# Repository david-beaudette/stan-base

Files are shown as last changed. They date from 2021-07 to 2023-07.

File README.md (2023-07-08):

### Install RPi Pico SDK
In a personal folder called projects (could be other):
```bash
cd ~/projects
mkdir pico
cd pico
git clone -b master https://github.com/raspberrypi/pico-sdk.git
cd pico-sdk
git submodule update --init
cd ..
git clone -b master https://github.com/raspberrypi/pico-examples.git
sudo apt update
sudo apt install cmake gcc-arm-none-eabi libnewlib-arm-none-eabi build-essential
cd pico-examples
mkdir build
cd build
echo "export PICO_SDK_PATH=~/projects/pico-sdk" >> ~/.bashrc
source ~/.bashrc
cmake -DCMAKE_BUILD_TYPE=Debug ..
make -j4

```
### Install OpenOCD and debugger
```bash
cd ~/projects/pico
sudo apt install automake autoconf build-essential texinfo libtool libftdi-dev libusb-1.0-0-dev
git clone https://github.com/raspberrypi/openocd.git --recursive --branch rp2040 --depth=1
cd openocd
./bootstrap
./configure --enable-ftdi --enable-sysfsgpio --enable-bcm2835gpio
make -j4
sudo make install
sudo apt install gdb-multiarch

```
### OpenOCD Setup
Add username to the plugdev group to allow non-sudo access to any USB device:
```bash
echo 'SUBSYSTEM=="usb", MODE="0660", GROUP="plugdev"' | sudo tee /etc/udev/rules.d/00-usb-permissions.rules
udevadm control --reload-rules
sudo usermod -a -G plugdev [username]
```
Log out and back in.

### Debugging session
To debug, start opencd in a seperate terminal in the ~/projects/pico/openocd folder:
```bash
cd ~/projects/pico/openocd
src/openocd -f interface/picoprobe.cfg -f target/rp2040.cfg -s tcl
```

### Current state
## Battery voltage reading
Battery / motor ground is decoupled from digital ground. That is good, however the voltage reading is offset and unreliable because of this. Apparently with proper star grounding the grounds could be connected together without issues. Otherwise the most reliable way of achieving this would be to use a seperate DC/DC converter and ADC on the high-power side, and opto-coupler on the digital link to RP2040. 

## Orientation sensor calibration
A proper procedure to calibrate the BNO055 should be written. Ideally it should be automated when/if the robot can achieve it by itself.

## Serial communication with head
The link between base and head (ROS-based) was not completed yet.

## Stability
Finish test_ctl

## LCD
LCD is not working anymore...

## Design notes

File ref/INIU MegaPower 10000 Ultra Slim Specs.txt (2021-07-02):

Capacity: 10,000 mAh; 37Wh
Output: USB-C: DC 5V/3A Max; USB-A: DC 5V/3A Max
Input: Micro: DC 5V/2A Max; USB C: DC 5V/3A Max Charging Time (via 5V/2A Charger): 5-6 hours
Included in the box: - 10000mAh portable charger*1 - Micro USB cable*1, travel pouch*1, user manual*1
Product materials: PowerBank: rubber covered plastic case with aluminum decorative elements / Cable: TPE, Nylon 
Connections: USB-A 
Length: 5.20 in / 13.21 cm 
Width: 2.70 in / 6.86 cm 
Height: 0.50 in / 1.27 cm 
Weight: 0.46 lbs / 0.21 kg

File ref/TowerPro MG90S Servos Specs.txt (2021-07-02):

Specification:
Weight: 13.4g
Dimension: 22.8×12.2×28.5mm
Stall torque: 1.8kg/cm (4.8V); 2.2kg/cm (6.6V)
Operating speed: 0.10sec/60degree (4.8V); 0.08sec/60degree (6.0V)
Operating voltage: 4.8V
Temperature range: 0 to 55decC
Dead band width: 1us
Power Supply: Through External Adapter
servo wire length: 25 cm
Servo Plug: JR (Fits JR and Futaba)
servo arms &screws included
It’s universal “S” type connector that fits most receivers, including Futaba, JR, Hitec ,GWS, Cirrus, Blue Bird, Blue Arrow, Corona, Berg, Spektrum.
CE &RoHS approved

We have upgraded our servo gear set and shaft to aluminum 6061-T6.
It is stronger and lighter than copper.

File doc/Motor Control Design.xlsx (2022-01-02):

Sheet: Constants
Clock Frequency (Hz) | 1000000
Steps per turn | 200
Microsteps per step | 8
Degrees per step | 1.8

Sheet: Speed
Pulse period (s) | Pulse ticks | Counter compare value | Overflow target | Pulses per sec | Steps per sec | Rotation rate (deg/s) | Result deg for 1 s | Rev per sec | Rotation rate (rad/s) | Pace (s/rad) | T std dev | Jitter (%)
0.000119516 | 119.516 | 119.516 | 0 | 8367.081 | 1045.885 | 1882.593 | 1882.800 | 5.229425349 | 32.8574 | 0.030 | 4.50596e-07 | 0.38%
0.008728 | 8728 | 8728 | 0 | 114.574 | 14.322 | 25.779 | 25.200 | 0.07160861595 | 0.4499 | 2.223 | 4.4247e-07 | 0.01%
0.015342 | 15342 | 15342 | 0 | 65.181 | 8.148 | 14.666 | 14.400 | 0.04073784383 | 0.2560 | 3.907 | 3.4638e-07 | 0.002257723895%
0.061367 | 61367 | 61367 | 0 | 16.295 | 2.037 | 3.666 | 3.600 | 0.01018462692 | 0.0640 | 15.627 | 2.9032e-07 | 0.0004730881418%

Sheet: Test Output
Speed update:
speed_f32 32.86
pol ticks tgt (f32) 956.02
pol ticks tgt 956
pol ticks cur 0
current timer value 27786
next compare value 28742
num overflows 0
OCR1A value 28742
TIMSK value 6
Left motor is stopped (current pos 1882.80 deg).
Right motor is stopped (current pos 27.00 deg).
Speed update:
speed_f32 0.45
pol ticks tgt (f32) 69813.18
pol ticks tgt 69813
pol ticks cur 0
current timer value 24616
next compare value 94429
num overflows 1
OCR1A value 28893
TIMSK value 6
Left motor is stopped (current pos 25.20 deg).
Right motor is stopped (current pos 27.00 deg).
Speed update:
speed_f32 0.26
pol ticks tgt (f32) 122718.46
pol ticks tgt 122718
pol ticks cur 0
current timer value 18599
next compare value 141317
num overflows 2
OCR1A value 10245
TIMSK value 6
Left motor is stopped (current pos 14.40 deg).
Right motor is stopped (current pos 27.00 deg).
Speed update:
speed_f32 0.06
pol ticks tgt (f32) 490873.84
pol ticks cur 0
current timer value 12622
next compare value 503495
num overflows 7
OCR1A value 44743
TIMSK value 6
Left motor is stopped (current pos 3.60 deg).
Right motor is stopped (current pos 27.00 deg).

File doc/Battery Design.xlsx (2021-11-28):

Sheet: Feuil1
State of Charge (%) | Voltage (V) | Analog count | F0 | F1 | F2 | F3 | Diff SoC (%)
100 | 12.6 | 3755 | 0.00000053 | -0.00396 | 7.46484 | 99.52417005 | 0.48
95 | 12.45 | 3711.309524 | 0.00000053 | -0.00399 | 7.55132 | 94.32312696 | 0.68
90 | 12.33 | 3676.357143 | 0.00000053 | -0.00401 | 7.62197 | 90.12365534 | -0.12
85 | 12.25 | 3653.055556 | 0.00000053 | -0.00402 | 7.66980 | 87.23095446 | -2.23
80 | 12.07 | 3600.626984 | 0.00000053 | -0.00405 | 7.77953 | 80.21527967 | -0.22
75 | 11.95 | 3565.674603 | 0.00000053 | -0.00406 | 7.85432 | 74.96738226 | 0.03
70 | 11.86 | 3539.460317 | 0.00000053 | -0.00408 | 7.91126 | 70.63443217 | -0.63
65 | 11.74 | 3504.507937 | 0.00000053 | -0.00410 | 7.98833 | 64.217946 | 0.78
60 | 11.62 | 3469.555556 | 0.00000053 | -0.00412 | 8.06671 | 56.9453805 | 3.05
55 | 11.56 | 3452.079365 | 0.00000053 | -0.00413 | 8.10639 | 52.9452693 | 2.05
50 | 11.51 | 3437.515873 | 0.00000053 | -0.00413 | 8.13971 | 49.40985029 | 0.59
45 | 11.45 | 3420.039683 | 0.00000053 | -0.00414 | 8.17999 | 44.91013486 | 0.09
40 | 11.39 | 3402.563492 | 0.00000053 | -0.00415 | 8.22059 | 40.11365542 | -0.11
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

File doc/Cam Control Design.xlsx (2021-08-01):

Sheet: Speed
Prescaler idx | Prescaler | Tick duration (s) | Tick duration (ns) | TOF Period (s) | Number of TOF | Integer num TOF | Achievable period (s) | PWM period error (%) | PWM resolution (%)
1 | 2 | 0.000000125 | 125 | 0.000032 | 625.0000 | 625 | 0.0200000 | 0.0% | 0.0006%
2 | 4 | 0.000000250 | 250 | 0.000064 | 312.5000 | 312 | 0.0199680 | 0.2% | 0.0013%
3 | 8 | 0.000000500 | 500 | 0.000128 | 156.2500 | 156 | 0.0199680 | 0.2% | 0.0025%
4 | 16 | 0.000001000 | 1000 | 0.000256 | 78.1250 | 78 | 0.0199680 | 0.2% | 0.0050%
5 | 32 | 0.000002000 | 2000 | 0.000512 | 39.0625 | 39 | 0.0199680 | 0.2% | 0.0100%
6 | 64 | 0.000004000 | 4000 | 0.001024 | 19.5312 | 19 | 0.0194560 | 2.7% | 0.0206%
7 | 128 | 0.000008000 | 8000 | 0.002048 | 9.7656 | 9 | 0.0184320 | 7.8% | 0.0434%
8 | 256 | 0.000016000 | 16000 | 0.004096 | 4.8828 | 4 | 0.0163840 | 18.1% | 0.0977%
9 | 512 | 0.000032000 | 32000 | 0.008192 | 2.4414 | 2 | 0.0163840 | 18.1% | 0.1953%
10 | 1024 | 0.000064000 | 64000 | 0.016384 | 1.2207 | 1 | 0.0163840 | 18.1% | 0.3906%
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

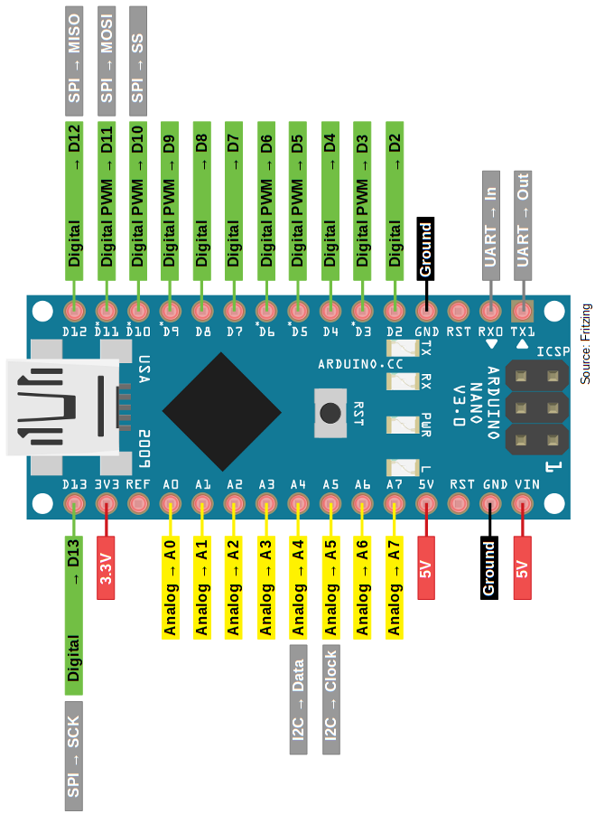
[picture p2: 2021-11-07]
ref/ArduinoNano/Arduino-Nano-Pinout-1.png

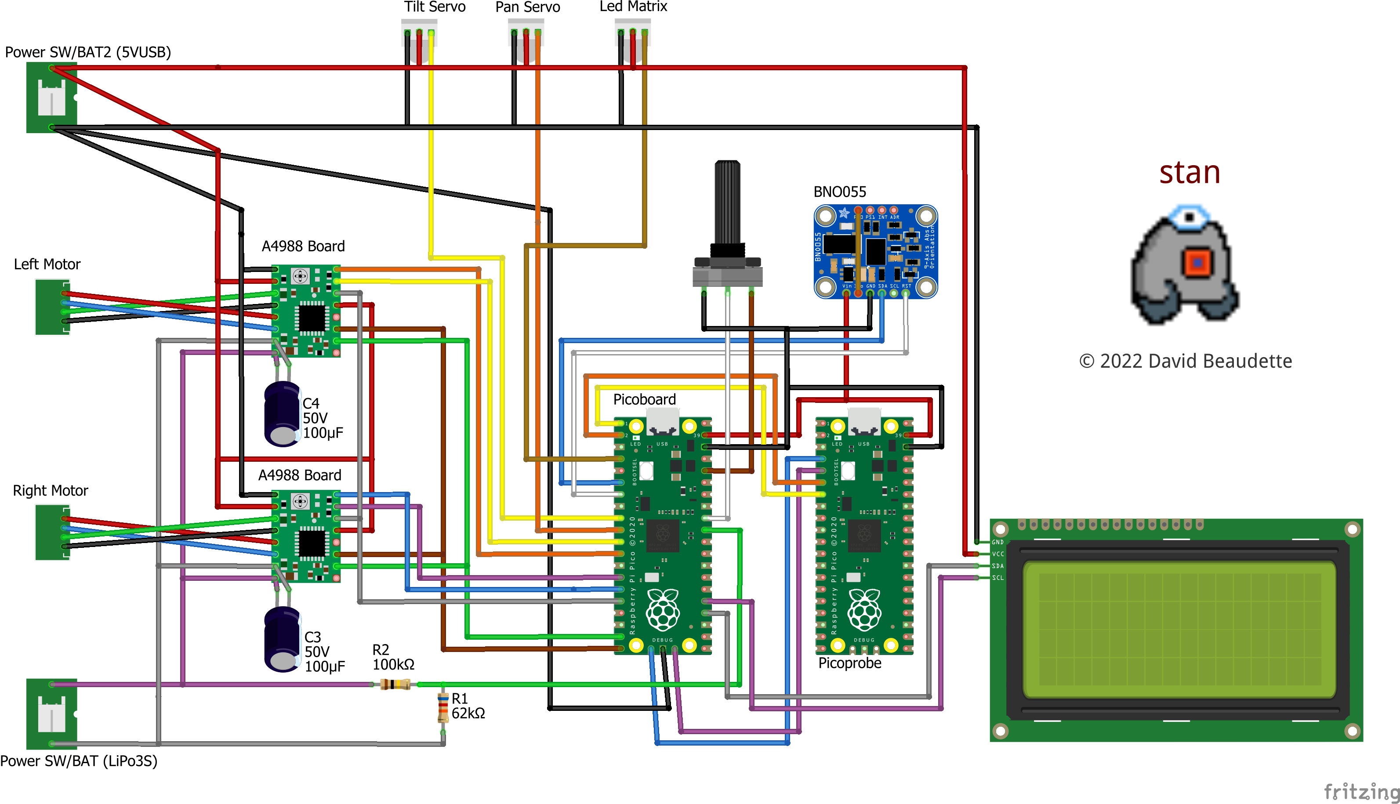
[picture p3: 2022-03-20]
doc/InterconnexionDiagram.png

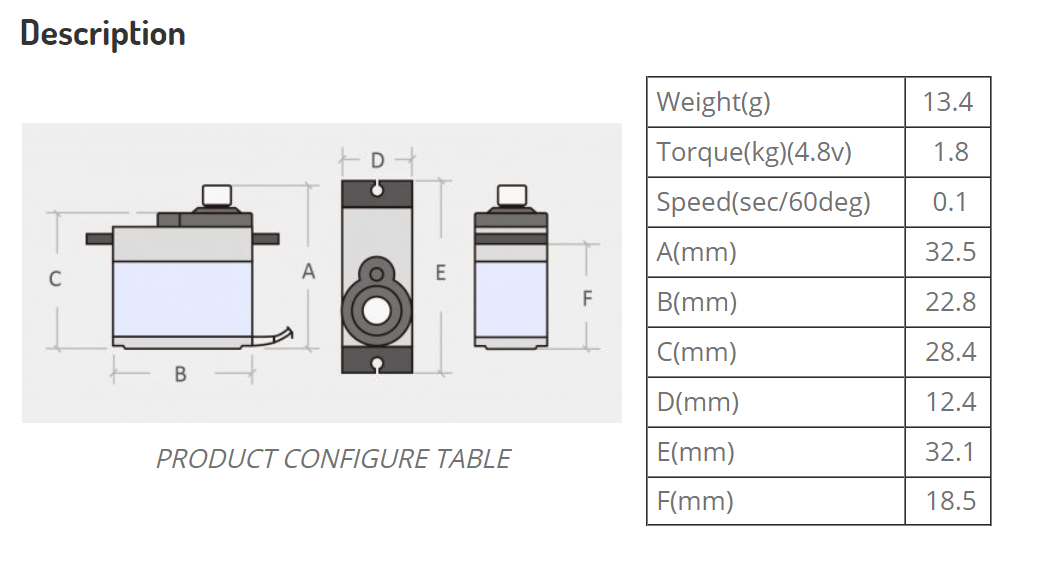
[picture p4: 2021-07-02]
ref/TowerPro MG90S Servos Dimensions.png

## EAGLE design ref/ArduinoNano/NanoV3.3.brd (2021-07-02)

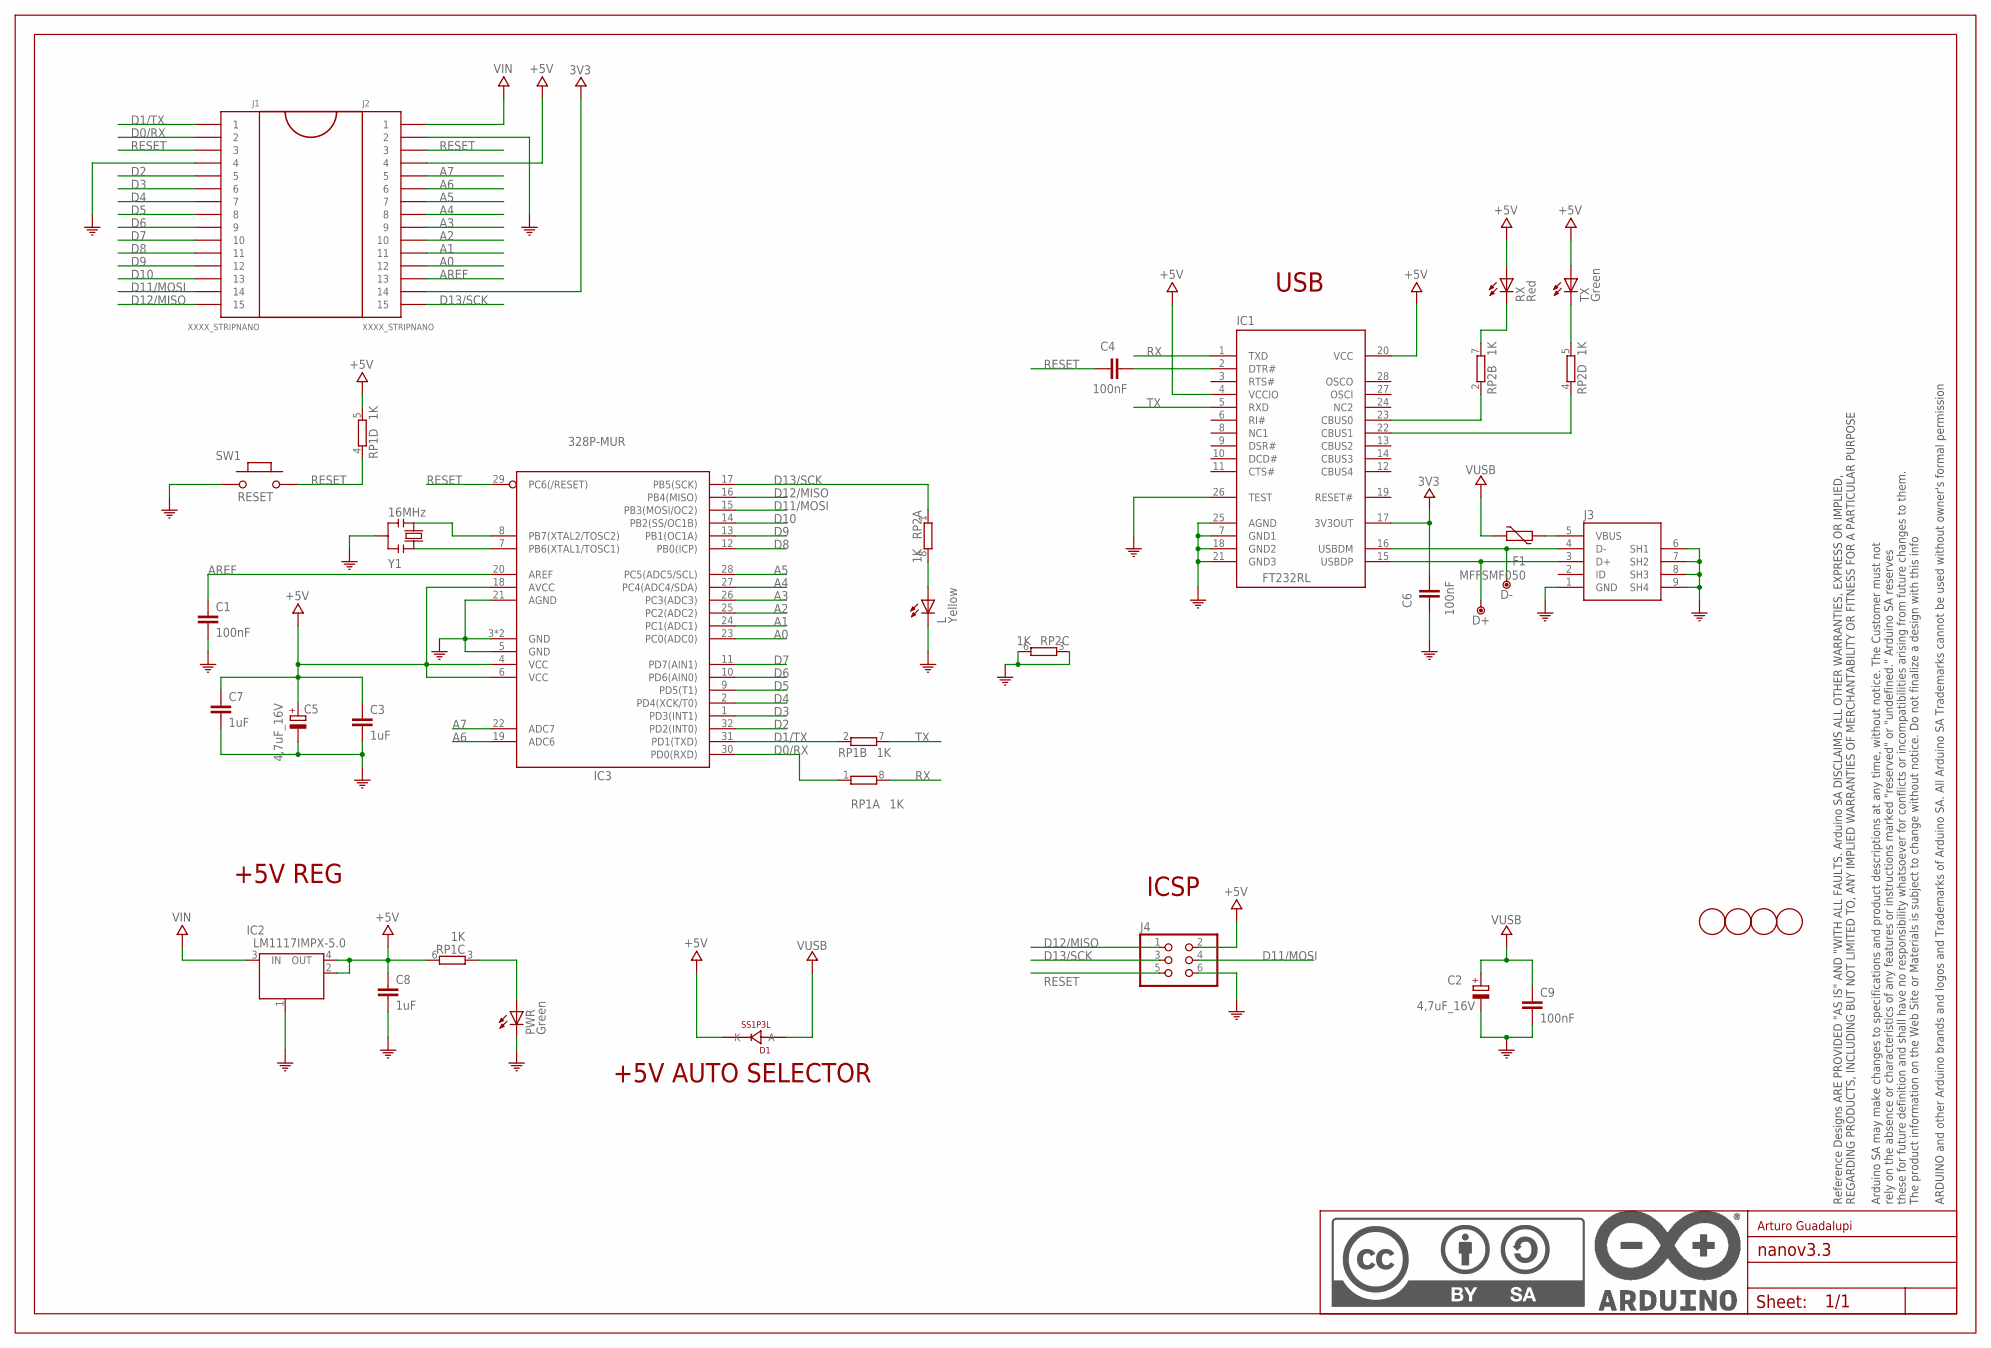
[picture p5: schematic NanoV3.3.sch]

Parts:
C1, C4, C6, C9: 100nF; C0603-ROUND
C2, C5: 4,7uF_16V; TAN-A
C3, C7, C8: 1uF; C0603-ROUND
D1: SS1P3L; DO220AAL
D+: DNP; TP-1.00MM
D-: DNP; TP-1.00MM
F1: MFFSMF050; 0603-1608X90N
FRAME1: DNP; FRAME
IC1: FT232RL; SSOP28
IC2: LM1117IMPX-5.0; LINEAR_SOT223
IC3: 328P-MUR; VQFN32
J1, J2: XXXX_STRIPNANO; HEAD15-NOSS
J3: 0219_14850; USB-MINI-B_2
J4: 0114_PH254-203DF118A00V; 2X03
L: Yellow; CHIPLED_0805
PWR: Green; CHIPLED_0805
RP1, RP2: 1K; CAY16
RX: Red; CHIPLED_0805
SW1: RESET; SMD_157SW
TX: Green; CHIPLED_0805
U$4, U$5, U$53, U$54: DNP; FD-1-1.5
Y1: 16MHz; RESONATOR

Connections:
3V3: C6.2, IC1.17 (3V3OUT), J2.14
+5V: C3.1, C5.1 (+), C7.1, C8.1, D1.P$1 (K), IC1.4 (VCCIO), IC1.20 (VCC), IC2.2 (OUT), IC2.4 (OUT), IC3.4 (VCC), IC3.6 (VCC), IC3.18 (AVCC), J2.4, J4.2, RP1.5 (2), RP1.6 (2), RX.A, TX.A
A0: IC3.23 (PC0(ADC0)), J2.12
A1: IC3.24 (PC1(ADC1)), J2.11
A2: IC3.25 (PC2(ADC2)), J2.10
A3: IC3.26 (PC3(ADC3)), J2.9
A4: IC3.27 (PC4(ADC4/SDA)), J2.8
A5: IC3.28 (PC5(ADC5/SCL)), J2.7
A6: IC3.19 (ADC6), J2.6
A7: IC3.22 (ADC7), J2.5
AREF: C1.1, IC3.20 (AREF), J2.13
COM: C1.2, C2.2 (-), C3.2, C5.2 (-), C6.1, C7.2, C8.2, C9.2, IC1.7 (GND1), IC1.18 (GND2), IC1.21 (GND3), IC1.25 (AGND), IC1.26 (TEST), IC2.1 (GND/ADJ), IC3.3 (GND), IC3.5 (GND), IC3.21 (AGND), IC3.33 (GND), J1.4, J2.2, J3.1 (GND), J3.6 (SH1), J3.7 (SH2), J3.8 (SH3), J3.9 (SH4), J4.6, L.C, PWR.C, RP2.3 (1), RP2.6 (2), SW1.1, Y1.2
D0/RX: IC3.30 (PD0(RXD)), J1.2, RP1.1
D1/TX: IC3.31 (PD1(TXD)), J1.1, RP1.2 (1)
D2: IC3.32 (PD2(INT0)), J1.5
D3: IC3.1 (PD3(INT1)), J1.6
D4: IC3.2 (PD4(XCK/T0)), J1.7
D5: IC3.9 (PD5(T1)), J1.8
D6: IC3.10 (PD6(AIN0)), J1.9
D7: IC3.11 (PD7(AIN1)), J1.10
D8: IC3.12 (PB0(ICP)), J1.11
D9: IC3.13 (PB1(OC1A)), J1.12
D10: IC3.14 (PB2(SS/OC1B)), J1.13
D11/MOSI: IC3.15 (PB3(MOSI/OC2)), J1.14, J4.4
D12/MISO: IC3.16 (PB4(MISO)), J1.15, J4.1
D13/SCK: IC3.17 (PB5(SCK)), J2.15, J4.3, RP2.1
unnamed: IC3.8 (PB7(XTAL2/TOSC2)), Y1.3
unnamed: IC3.7 (PB6(XTAL1/TOSC1)), Y1.1
unnamed: PWR.A, RP1.3 (1)
unnamed: C4.2, IC1.2 (DTR#)
unnamed: D+.X, IC1.15 (USBDP), J3.3 (D+)
unnamed: D-.X, IC1.16 (USBDM), J3.4 (D-)
unnamed: L.A, RP2.8 (2)
unnamed: IC1.23 (CBUS0), RP2.2 (1)
unnamed: IC1.22 (CBUS1), RP2.4 (1)
unnamed: RP2.5 (2), TX.C
unnamed: F1.2, J3.5 (VBUS)
unnamed: RP2.7 (2), RX.C
RESET: C4.1, IC3.29 (PC6(/RESET)), J1.3, J2.3, J4.5, RP1.4 (1), SW1.2
RX: IC1.1 (TXD), RP1.8 (2)
TX: IC1.5 (RXD), RP1.7 (2)
VIN: IC2.3 (IN), J2.1
VUSB: C2.1 (+), C9.1, D1.P$2 (A), F1.1

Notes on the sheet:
+5V REG
ICSP
USB
+5V AUTO SELECTOR
Arturo Guadalupi



Board: 2 copper layers, 43.2 x 17.8 mm, 33 parts (17 on the bottom side), 43 nets.

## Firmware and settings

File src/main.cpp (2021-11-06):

/** STAN THE STANDING ROBOT
   Program for the base / low-level controller 
   by David Beaudette   
**/

// Libraries
#include "Arduino.h"
#include "TaskScheduler.h"

// Project headers
#include "nav.h"
#include "ctl.h"
#include "cam.h"
#include "bat.h"
#include "PID_v1.h"
#include "Base2Head.hpp"
#include "Head2Base.hpp"
#include "fletcher_impl.hpp"

// Function declaration
void gnc_task_run();
void blink();
void pub_slow();
void pub_fast();
void check_sys();

// Serial callbacks
void serial_cmd_recv();
size_t read_bytes(byte *buffer, size_t n);

// Task configuration
float gnc_task_dt = 0.01f;

Scheduler runner;

Task gnc_task((int)(gnc_task_dt * 1000.0f), TASK_FOREVER, &gnc_task_run);
Task blink_task(500, TASK_FOREVER, &blink);
Task pub_slow_task(1000, TASK_FOREVER, &pub_slow);
Task pub_fast_task(10, TASK_FOREVER, &pub_fast);
Task check_sys_task(1000, TASK_FOREVER, &check_sys);

// Health LED
bool blink_state = false;

// System status is initialising
uint8_t system_status_i = BASE_STATUS_PREINIT;
uint8_t system_err_i = BASE_ERR_NONE;
uint8_t seq_num_slow = 0U;
uint8_t seq_num_fast = 0U;
uint8_t seq_recv_last = 255U;
uint16_t crc_error_count = 0U;
uint16_t num_bytes_written_prev = 0U;

// Global variables
double pitch_cur_deg = 0.0;
double pitch_tgt_deg = -7.2;
double speed = 0.0;
bool motors_enabled = false;
uint8_t cam_tilt_mode_ui8 = 1; // 0: Absolute tilt; 1: Relative tilt
float cam_pan_deg_f32 = 0.0f;
float cam_tilt_deg_f32 = 0.0f; 
float cam_tilt_offset_deg_f32 = 0.0f; // Only used in mode 1

// Instantiate controller
double Kp = 1.0, Ki = 0, Kd = 0;
PID ctl_pid(&pitch_cur_deg, &speed, &pitch_tgt_deg,
            Kp, Ki, Kd, DIRECT);

void setup()
{
  // Initialise serial communication
  Serial.begin(115200);

  // Initialise tasks
  nav_init(gnc_task_dt);
  ctl_init();
  cam_init();

  ctl_pid.SetMode(AUTOMATIC);
  ctl_pid.SetSampleTime(10);
  ctl_pid.SetOutputLimits(-1000.0, 1000.0);

  runner.init();

  runner.addTask(gnc_task);
  runner.addTask(blink_task);
  runner.addTask(pub_slow_task);
  runner.addTask(pub_fast_task);
  runner.addTask(check_sys_task);

  gnc_task.enable();
  blink_task.enable();
  pub_slow_task.enable();
  pub_fast_task.enable();
  check_sys_task.enable();
}

void loop()
{
  runner.execute();
  serial_cmd_recv();
}

// From SimpleSerialProtocol Core: Serial.readBytes is SLOW
// this one is much faster, but has no timeout
size_t read_bytes(byte *buffer, size_t n)
{
  size_t num_bytes_read = 0;
  int c;
  while (num_bytes_read < n)
  {
    c = Serial.read();
    if (c < 0)
      break;
    *buffer++ = (byte)c; // buffer[i] = (int8_t)c;
    num_bytes_read++;
  }
  return num_bytes_read;
}

void gnc_task_run()
{
  // Update pitch measurement
  nav();

  // Update controller if motors are on and
  // initialisation phase is complete
  if (nav_get_filter_init())
  {
    pitch_cur_deg = nav_get_pitch();

    if (motors_enabled)
    {
      system_status_i = BASE_STATUS_RUNNING;
      ctl_pid.Compute();
      ctl_set_motor_speed(speed,
                          speed);
    }
    else
    {
      system_status_i = BASE_STATUS_MOTOR_OFF;
    }
    if (cam_tilt_mode_ui8 == 1U) {
      cam_tilt_deg_f32 = cam_set_tilt(pitch_cur_deg + 
                                      cam_tilt_offset_deg_f32);
    }
  }
  else
  {
    system_status_i = BASE_STATUS_FILTINIT;
  }
}

void blink()
{
  // Blink LED to indicate activity
  blink_state = !blink_state;
  digitalWrite(LED_BUILTIN, blink_state);
}

void pub_slow()
{
  // Compute sequence number
  if (seq_num_slow == UINT8_MAX)
  {
    seq_num_slow = 0U;
  }
  else
  {
    ++seq_num_slow;
  }

  // Build message and send
  Base2HeadSlow msg;
  msg.forebyte = BASE2HEAD_FOREBYTE_SLOW;
  msg.seq = seq_num_slow;
  msg.seq_recv_last = seq_recv_last;
  msg.crc_error_count = crc_error_count;
  msg.status = (system_status_i & 0x0F) + ((system_err_i & 0x0F) << 4);
  msg.batt_soc = bat_get_state_of_charge();
  msg.batt_volt = bat_get_last_voltage();
  msg.pitch_zero = pitch_tgt_deg;
  msg.pitch_filter_gain = nav_get_filter_gain();
  msg.pitch_ctl_gain_P = Kp;
  msg.pitch_ctl_gain_I = Ki;
  msg.pitch_ctl_gain_D = Kd;
  msg.crc = compute_fletcher16((uint8_t *)&msg,
                               sizeof(Base2HeadSlow) -
                                   sizeof(Head2BaseCommand::crc));

  Serial.write((uint8_t *)&msg, sizeof(msg));
}

void pub_fast()
{
  // Compute sequence number
  if (seq_num_fast == UINT8_MAX)
  {
    seq_num_fast = 0U;
  }
  else
  {
    ++seq_num_fast;
  }

  // Build message and send
  Base2HeadFast msg;
  msg.forebyte = BASE2HEAD_FOREBYTE_FAST;
  msg.seq = seq_num_fast;
  msg.status = (system_status_i & 0x0F) + ((system_err_i & 0x0F) << 4);
  msg.acc_count = accel_isr_count_ui32;
  msg.cam_pan_pct = cam_pan_deg_f32;
  msg.cam_tilt_pct = cam_tilt_deg_f32;
  msg.pitch_cmd = pitch_tgt_deg;
  msg.pitch_est = pitch_cur_deg;
  msg.speed_cmd[0] = speed;
  msg.speed_cmd[1] = speed;
  msg.acc_x_mes = ax;
  msg.acc_y_mes = ay;
  msg.acc_z_mes = az;
  msg.w_mes = gy * gyr_analog2degps;
  msg.crc = compute_fletcher16((uint8_t *)&msg,
                               sizeof(Base2HeadFast) -
                                   sizeof(Head2BaseCommand::crc));

  num_bytes_written_prev = Serial.write((uint8_t *)&msg, sizeof(msg));
}

void check_sys()
{
  if (bat_check_level())
  {
    system_err_i &= ~BASE_ERR_LOW_BAT;
  }
  else
  {
    system_err_i |= BASE_ERR_LOW_BAT;
  }
}

void serial_error_cb(uint8_t err_num_i)
{
  system_err_i = BASE_ERR_SERIAL;
}

void serial_cmd_recv()
{
  Head2BaseCommand *msg = NULL;
  byte recv_buf[SERIAL_RX_BUFFER_SIZE];
  size_t num_bytes_avail = Serial.available();
  size_t buf_iter = 0;
  if (num_bytes_avail >= sizeof(Head2BaseCommand))
  {
    // Read the entire serial buffer and look for
    // the command packet start byte
    read_bytes(recv_buf, num_bytes_avail);
    while (buf_iter < SERIAL_RX_BUFFER_SIZE)
    {
      if (recv_buf[buf_iter] == HEAD2BASE_FOREBYTE_CMD)
      {
        msg = (Head2BaseCommand *)recv_buf;
      }
      ++buf_iter;
    }
    // Interpret message if start of packet was found
    if (msg)
    {
      seq_recv_last = msg->seq;
      uint16_t crc = compute_fletcher16((uint8_t *)msg,
                                        sizeof(Head2BaseCommand) -
                                            sizeof(Head2BaseCommand::crc));

      if (crc == msg->crc)
      {
        // Check which command was received
        switch (msg->type)
        {
        case InitialiseFilter:
          nav_set_filter_gain(msg->val1);
          nav_set_avg_len(msg->val2);
          nav_reset_filter();
          break;
        case TunePitchControl1:
          Kp += msg->val1;
          Ki += msg->val2;
          ctl_pid.SetTunings(Kp, Ki, Kd);
          break;
        case TunePitchControl2:
          Kd += msg->val1;
          ctl_pid.SetTunings(Kp, Ki, Kd);
          break;
        case PanTiltAbsCamera:
          cam_tilt_mode_ui8 = 0;
          cam_pan_deg_f32 = cam_set_pan(msg->val1);
          cam_tilt_deg_f32 = cam_set_tilt(msg->val2);
          break;
        case PanTiltRelCamera:
          cam_tilt_mode_ui8 = 1;
          cam_pan_deg_f32 = cam_set_pan(msg->val1);
          cam_tilt_offset_deg_f32 = msg->val2;
          break;
        case LevelCamera:
          cam_tilt_mode_ui8 = 1;
          cam_pan_deg_f32 = cam_set_pan(0.0f);
          cam_tilt_offset_deg_f32 = 0.0f;
          break;
        case TuneZeroPitch:
          pitch_tgt_deg += msg->val1;
          break;
        case SetSpeed:
          break;
        case SetTurnRate:
          break;
        case LedBlinkRate:
          blink_task.setInterval((unsigned long)(msg->val1 * 1000.0f));
          break;
        case SetRunningState:
          if (msg->val1 > 0.5f)
          {
            motors_enabled = true;
            ctl_enable_motors();
          }
          else
          {
            motors_enabled = false;
            ctl_disable_motors();
          }
          break;
        default:
          break;
        }
      }
      else
      {
        ++crc_error_count;
      }
    }
  }
}

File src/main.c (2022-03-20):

/** STAN THE STANDING ROBOT
   Program for the base / low-level controller
   by David Beaudette
**/

#include "hardware/i2c.h"
#include "pico/stdlib.h"
#include "cam.h"
#include "uip.h"
#include "nav.h"

int main() {
  const uint LED_PIN = PICO_DEFAULT_LED_PIN;
  gpio_init(LED_PIN);
  gpio_set_dir(LED_PIN, GPIO_OUT);
  stdio_init_all();

  cam_init();
  uip_init();
  nav_init();

  cam_center();

  while (true) {
    gpio_put(LED_PIN, 1);
    sleep_ms(500);
    gpio_put(LED_PIN, 0);
    sleep_ms(500);
  } 

  cam_disable();

  return 0;
}

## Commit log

2021-03-06 First code with motor driver.
2021-03-07 Interfaced with accelerometer and gyroscope.
2021-03-07 Setup ISR for accelerometer data.
2021-03-08 Added complementary filter and initial sensor bias / offset estimation.
2021-03-12 Motors now orient with pitch. Integrated stepper library.
2021-03-21 Added unit test to determine the motor top speed.
2021-03-28 Modified controller to use timer 1 without library.
    [Motor Control Design.xlsx]
2021-03-28 Fixed a few bugs. Still holes in the signal.
2021-04-01 Succeeded in generating the left motor pulse train.
    [Motor Control Design.xlsx]
2021-04-02 Generalised pulse generation for both motors. Still not working.
2021-04-03 Motor control test passed.
    [Motor Control Design.xlsx]
2021-04-03 Modified to perform velocity control using pitch.
2021-04-04 Fixed accelerometer interrupt generation setting. Added state of charge computation to battery monitor function.
    [Battery Design.xlsx]
2021-04-04 Integrated PID library. Only compensating in one direction...
2021-04-18 Removed all serial prints except slow and fast packets.
2021-04-24 Optimised and protected complementary filter.
2021-04-25 Fixed gyro conversion from analog to deg/s.
2021-04-25 Added CRC to protocol. Reset pitch on filter init.
    [main.cpp]
2021-05-01 Now initialisation of filter only averages gyro noise.
    [main.cpp]
2021-05-08 Added command interface for motor enabling.
2021-05-15 Added tunable filter gain.
2021-05-16 Improved gyro bias estimation by using float.
2021-05-22 Prepared for PCB design
    [StanBase.kicad_pcb, StanBase.sch]
2021-05-23 Added more components for PCB design
    [ArduinoNanoSchematics.kicad_pcb, ArduinoNanoSchematics.sch, NanoV3.3.brd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]
2021-05-23 Added project specific libraries
    [StanBase.sch]
2021-05-30 Relocated references and created Fritzing diagram.
    [ArduinoNanoSchematics.kicad_pcb, ArduinoNanoSchematics.sch, NanoV3.3.brd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]
2021-05-31 Finished first version of interconnexion diagram.
    [StanBase.fzz]
2021-06-04 Added interconnexion diagram version with connectors and another with protoboard.
    [StanBaseBB.fzz, StanBaseProto.fzz]
2021-07-02 Set Arduino port for Linux
2021-07-31 Updated protoboard design.
    [StanBaseProto.fzz]
2021-07-31 Started integrating camera module.
2021-07-31 Drafted servo driver based on timer 2 with 2 channels. Test fails.
    [Cam Control Design.xlsx]
2021-08-01 Finished implementing camera pan tilt control.
    [Cam Control Design.xlsx]
2021-08-01 Eliminated some of the jitter when changing servo command.
2021-08-01 Implemented auto camera leveling.
2021-10-07 Updated protoboard drawing.
    [StanBaseBB.fzz]
2021-10-23 Added Pico reference
2021-11-06 Transferring code to RPi Pico. Dummy project was setup.
2021-11-07 Added RP2040 reference files and Fritzing designs.
    [StanBaseBBPico.fzz]
2021-11-07 Added hardware details.
    [StanBaseBBPico.fzz]
2021-11-07 Created connection diagram for pico.
    [StanBaseBB.fzz, StanBaseBBPico.fzz]
2021-11-13 Setup test build for camera control.
2021-11-13 Created files for unit test of camera control
2021-11-14 Finished implementing camera servo test.
2021-11-15 Added potentiometer mapping function.
    [Potentiometer Mapping.xlsx]
2021-11-15 Linked pot to camera pan.
2021-11-28 Update Battery Design.xlsx
    [Battery Design.xlsx]
2021-11-28 Implemented battery voltage / SoC reading. Added motor control.
2021-12-18 Finalised draft of speed to PWM counter conversion function.
2022-01-01 Completed PWM controller. Microstepping control remains.
2022-01-02 Finalised auto control of period for fast / slow speed. Added a second motor test using pot.
2022-01-02 Update Motor Control Design.xlsx
    [Motor Control Design.xlsx]
2022-01-02 Added pulse counter on PWM.
2022-01-07 Added PID and NAV functions.
2022-01-09 Added controller function that uses both the motor and pid functions.
2022-03-20 Created breadboard interconnexion diagram with LCD.
    [StanBaseBBPico.fzz]

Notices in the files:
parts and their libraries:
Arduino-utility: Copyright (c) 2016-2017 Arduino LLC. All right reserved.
